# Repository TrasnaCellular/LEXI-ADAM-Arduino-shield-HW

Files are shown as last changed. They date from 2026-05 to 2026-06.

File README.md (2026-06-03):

# Trasna LEXI-R10 Arduino schield board

The LEXI-ADAM UNO Shield is an open-source cellular expansion board for the Arduino UNO or Arduino UNO Q platforms. It uses the ultra-small LEXI-R10 series or ADAM-R11 series LTE Cat 1bis cellular modules. 

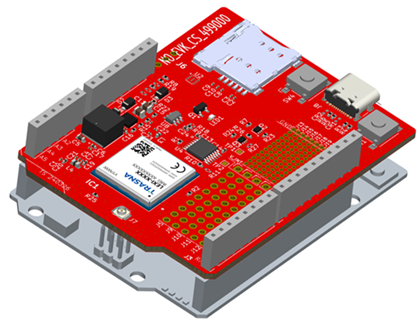
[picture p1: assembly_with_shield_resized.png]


The Cellular module can be turned ON/OFF and Reset by the Arduino board. The shield has its own step down to deliver power to the cellular module; the stepdown too can be turned ON/OFF by an Arduino GPIO to minimise power consumption. The input voltage range of the shield is the same as Arduino's range. 

The Arduino UNO  communicates with the Cellular module via UART, and by default, this communication is without RTS/CTS handshake. The shield already supports RTS/CTS handshake by easy soldering jumpers. The proper modifications must be made also to the MCU firmware of Arduino (R7FA4M1AB3CFM for UNO, or STM32U585 for UNO Q) to support hardware handshake. To achieve communication with the Linux system of Arduino UNO Q, the Arduino Bridge feature should be used. For even higher higher communication rates with the Linux system the USB port of the UNO Q must be connected to the USB port of the shield.
 
The shield also features two breadboarding areas for experimenting with own circuits. They have 2.54mm and 1.27mm pitch and are provided with 3.3Volts, 1.8Volts and GND for powering the circuits that the user might implement.

All the hardware design source files, including Schematic, PCB board, gerbers, stack-up, can be downloaded from the present repository. Also the firmware examples running on Arduino UNO R4 WIFI and on Arduino UNO Q can be found here.

The user guide explaining the board can be downloaded from: [LEXI-ADAM_Arduino_UNO_Shield_UserGuide](https://drive.google.com/file/d/1tEk1xlIRyrKd_FjjbZdSfsDOfKxhqTxc/view).

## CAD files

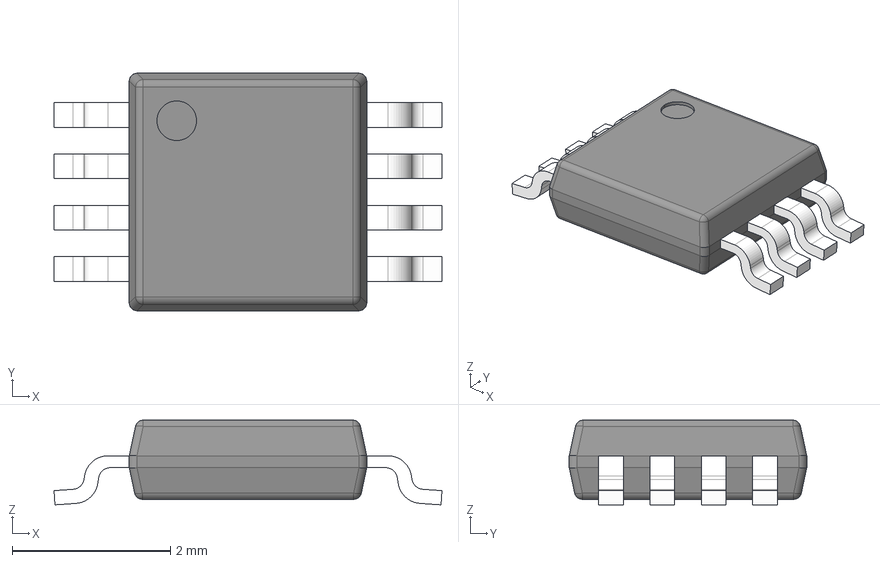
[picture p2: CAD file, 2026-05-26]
shield_design_library/3D/DGN0008G.stp
4.90 x 3.00 x 1.07 mm
BODY-DGN0008G
LEAD-DGN0008G x 8
PIN1_DGN0008G
DAP_DGN0008G

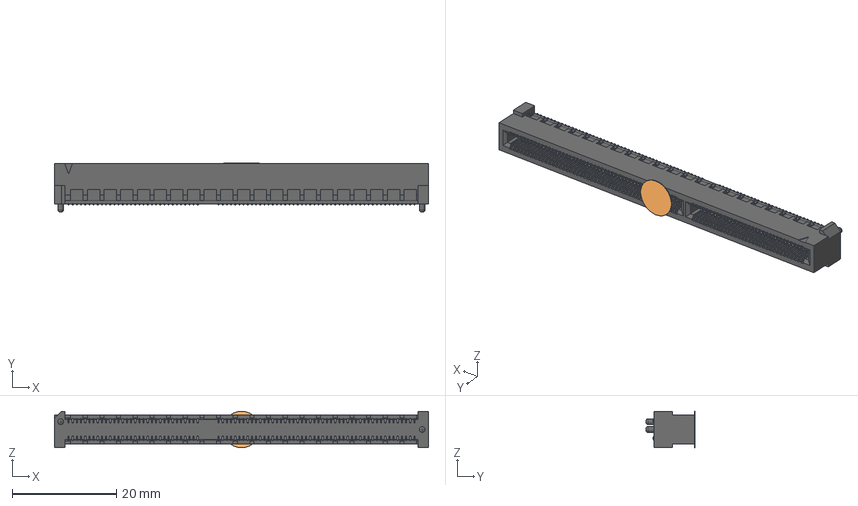
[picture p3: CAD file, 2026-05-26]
shield_design_library/3D/HSEC8-180-01-L-DV-A.step
71.8 x 9.43 x 7.01 mm
HSEC8-180-01-L-DV-A-Kter
C-188-02-Pin-32--L-01
C-188-02-Pin-32--L-012
C-188-02-Pin-48--L-01
C-188-02-Pin-48--L-012

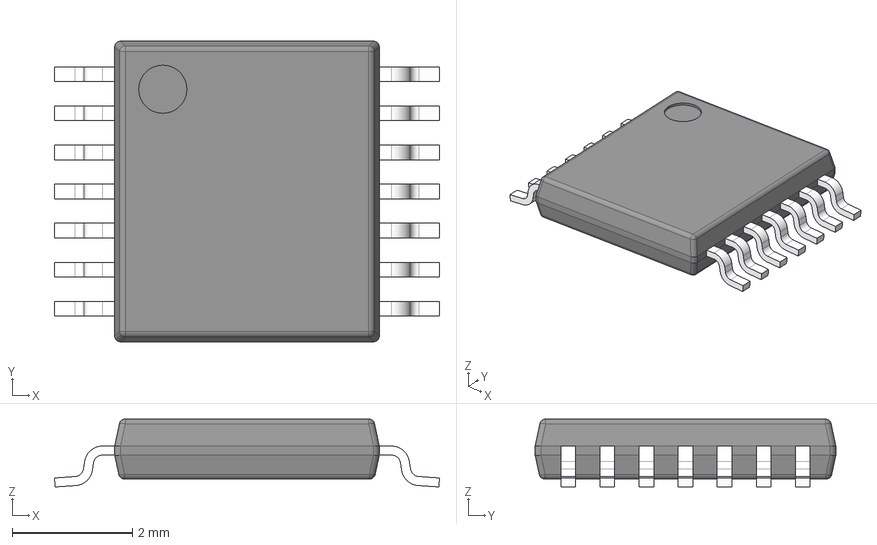
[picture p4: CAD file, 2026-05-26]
shield_design_library/3D/PW0014A.stp
6.40 x 5.00 x 1.13 mm
BODY-TSSOP
LEAD-TSSOP x 14
PIN1

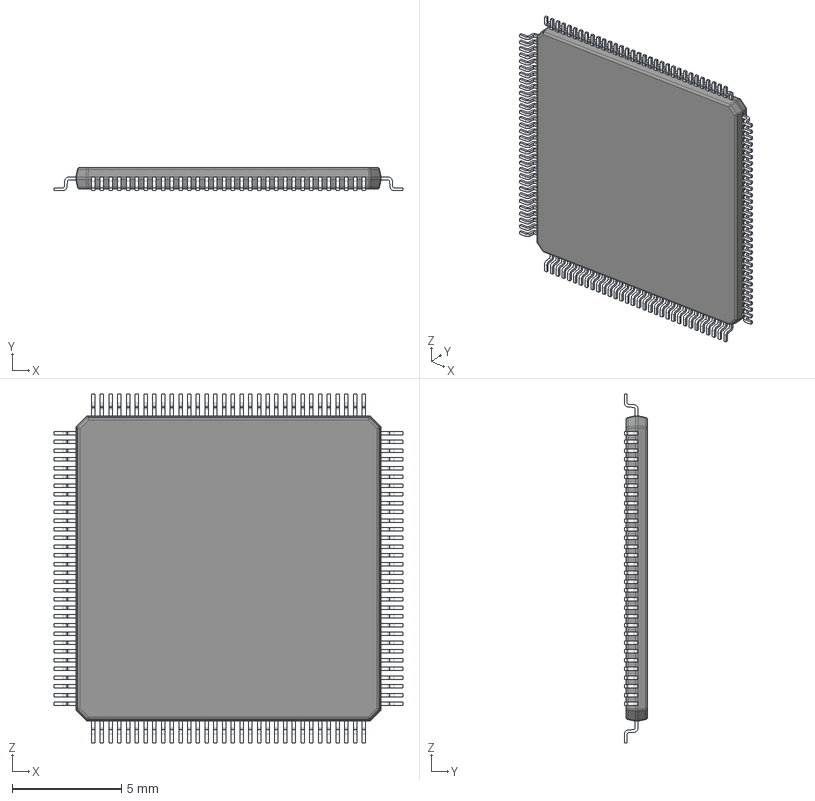
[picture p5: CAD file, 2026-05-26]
shield_design_library/3D/PDT0128A.stp
16.0 x 1.07 x 16.0 mm
BODY_VJX128A
LEAD_VJX128A x 128

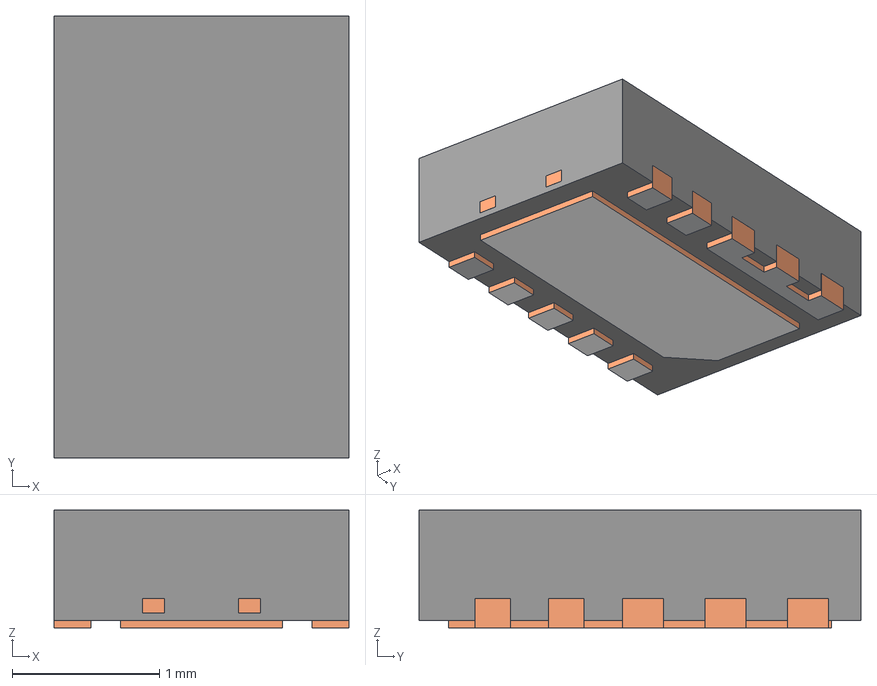
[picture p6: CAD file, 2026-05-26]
shield_design_library/3D/DML0010A.stp
2.00 x 3.00 x 0.8 mm
BODY-SON
FRAME-DML0010A
PIN1-ID

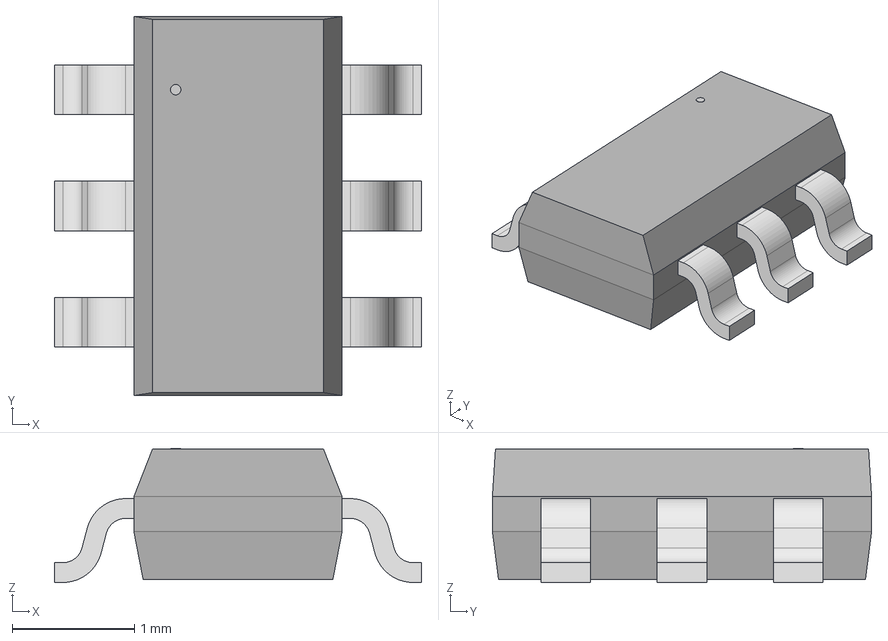
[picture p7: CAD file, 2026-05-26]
shield_design_library/3D/74LVC2G07GV_125_NEX.step
3.00 x 3.10 x 1.09 mm

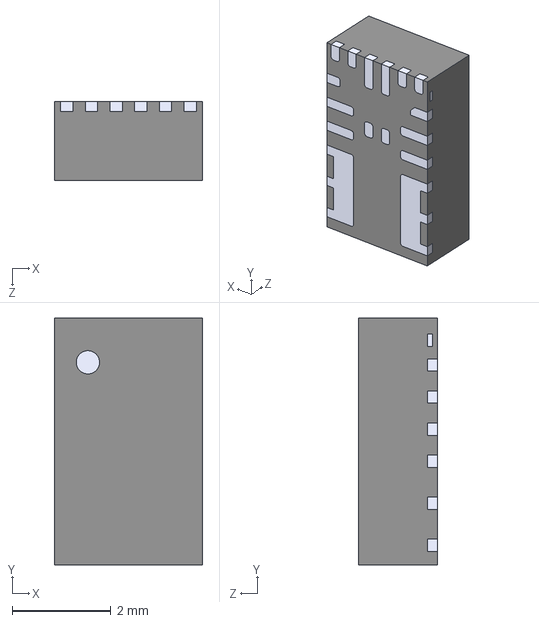
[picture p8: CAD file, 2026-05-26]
shield_design_library/3D/MPM3606AGQV.step
3.00 x 5.00 x 1.60 mm

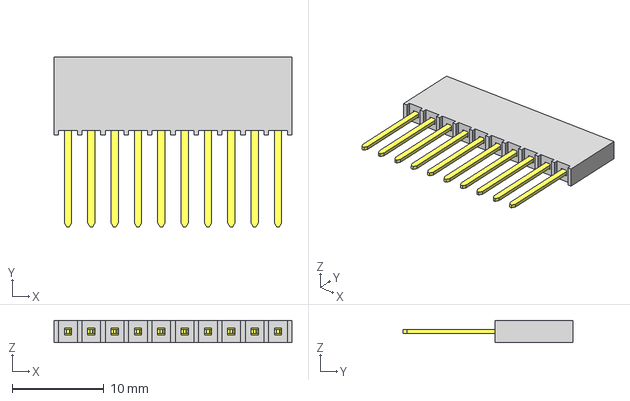
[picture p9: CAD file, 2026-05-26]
shield_design_library/3D/SSW-110-03-L-S.stp
25.9 x 18.5 x 2.41 mm
T1SSW-110-03-L-S
P2SSW-110-03-L-S

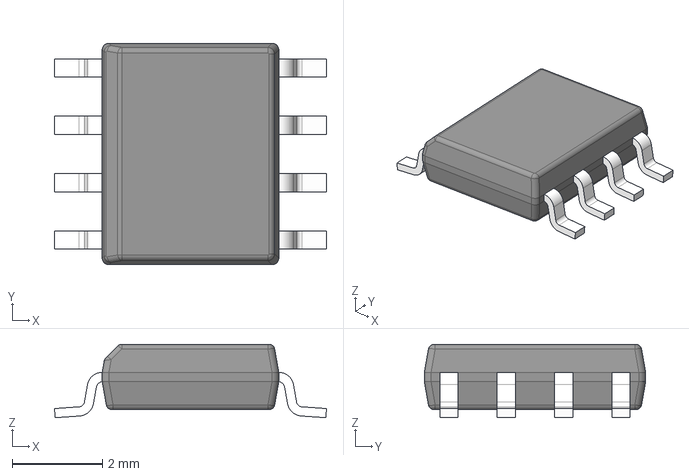
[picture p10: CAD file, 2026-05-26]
shield_design_library/3D/D0008A.stp
6.02 x 4.90 x 1.63 mm
BODY-SO
LEAD-D0008A x 8

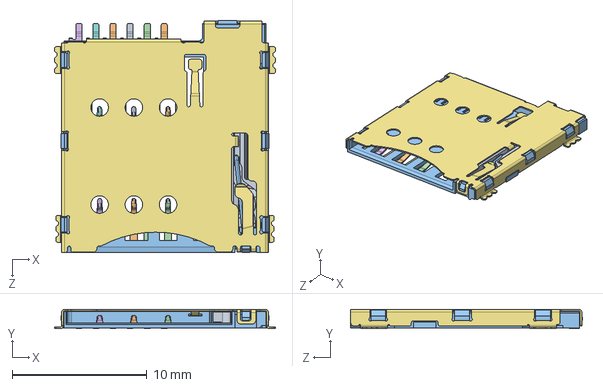
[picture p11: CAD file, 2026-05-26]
shield_design_library/3D/MSIM-2-A.stp
16.4 x 1.44 x 17.2 mm

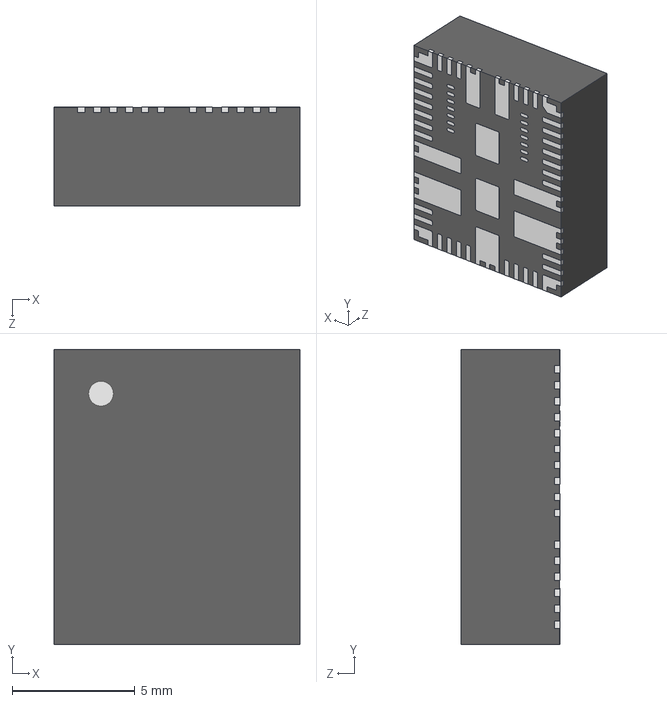
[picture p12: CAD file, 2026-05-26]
shield_design_library/3D/MPM3695GRF-25.step
10.0 x 12.0 x 4.01 mm

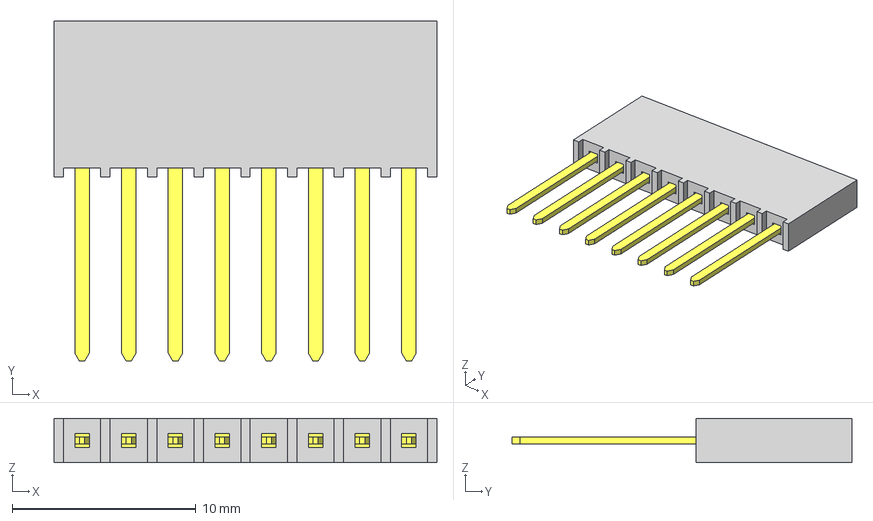
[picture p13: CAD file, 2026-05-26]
shield_design_library/3D/SSW-108-03-G-S.stp
20.8 x 18.5 x 2.41 mm
T1SSW-108-03-G-S
P2SSW-108-03-G-S

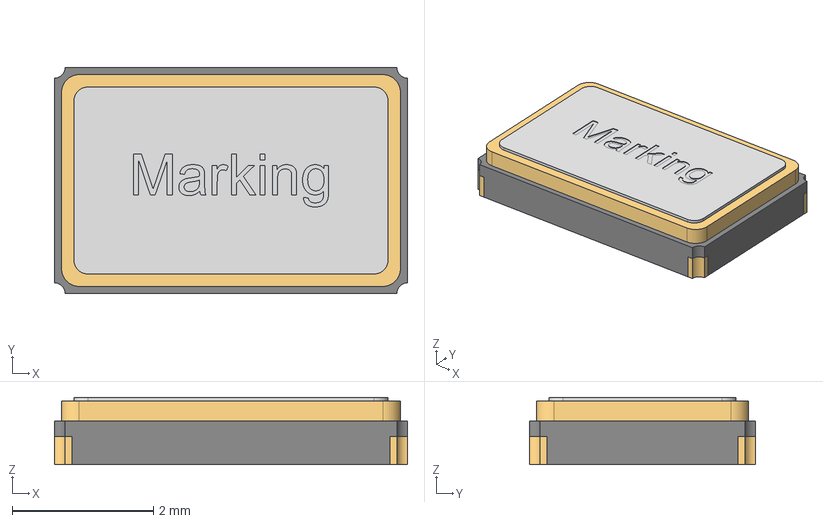
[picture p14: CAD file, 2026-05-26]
shield_design_library/3D/Download_STP_830059528 (rev1).stp
5.00 x 3.20 x 0.95 mm
Pins
Cover

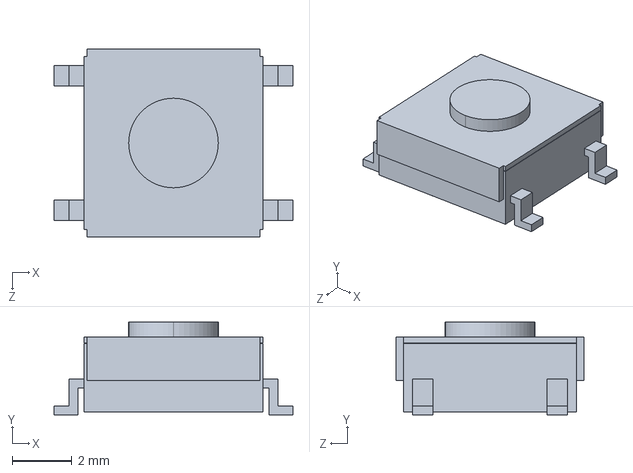
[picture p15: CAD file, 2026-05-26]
shield_design_library/3D/B3FS_1000.step
8.00 x 3.10 x 6.30 mm

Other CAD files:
shield_design_library/3D/DRL0006A.stp
shield_design_library/3D/21-0076E_MXM.step
shield_design_library/3D/CT3151-0.stp
shield_design_library/3D/CT3151-2.stp
shield_design_library/3D/Crystal_SMD_Abracon_ABM3B-4Pin_5.0x3.2mm.step
shield_design_library/3D/DCK0005A.stp
shield_design_library/3D/DDA0008J.stp
shield_design_library/3D/DGK0008A.stp
shield_design_library/3D/DRR0012G.stp
shield_design_library/3D/IND_BLM15_0402_MUR.step
shield_design_library/3D/IND_BLM18_0603_MUR.step
shield_design_library/3D/IND_IFSC-2020DE-01_VIS.step
shield_design_library/3D/LED_LTST-C190_LTO.step
shield_design_library/3D/LTST-C190KRKT.stp
shield_design_library/3D/LexiWithLabelTrasna.step
shield_design_library/3D/MAX4594EXK-T.step
shield_design_library/3D/MICROPAK6_1X1P45_ONS.step
shield_design_library/3D/PBS0032A.stp
shield_design_library/3D/PESD0402-140_LTF.step
shield_design_library/3D/QFN32_5X5MC_MCH.step
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

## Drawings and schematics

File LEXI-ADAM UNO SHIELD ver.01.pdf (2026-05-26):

1 | 2 | 3 | 4 | 5 | 6

A

BC

D

A

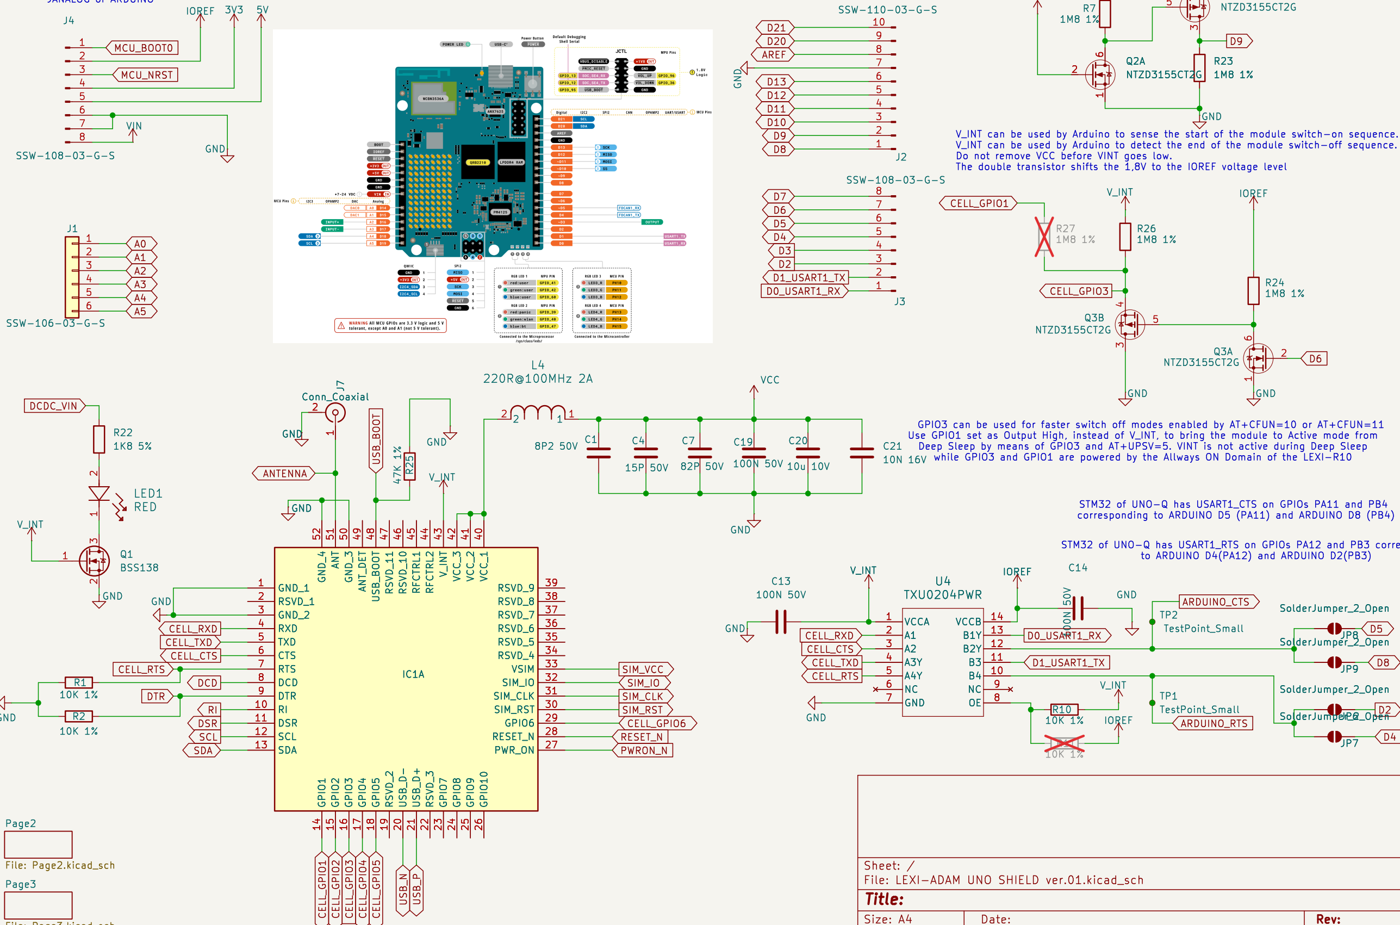
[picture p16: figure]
220R@100MHz; GND; J1 SSW-106-03-G-S; 8P2 50V GND; J4 SSW-108-03-G-S; IOREF 3V3; R²⁵ 47K ¹%; V_INT ² 1; LED1 RED; 82P 50V GND; VIN; CELL_GPIO3 SCL SDA CELL_TXD; PWRON_N; SIM_CLK; SIM_IO; CELL_RTS CELL_RXD; CELL_TXD; CELL_CTS; SIM_RST; CELL_GPIO1 DCD; ARDUINO_CTS CELL_GPIO6 SIM_VCC USB_P; ARDUINO_RTS DTR; D8D2D4 CELL_RTS; CELL_GPIO¹; D5 USB_N; ANTENNA RI; D6 DSR 2 GNDGND; V_INT; IOREF U4 TXU0204PWR; JP8 SolderJumper_2_Open; JP9 SolderJumper_2_Open; Q2A NTZD3155CT2G 2
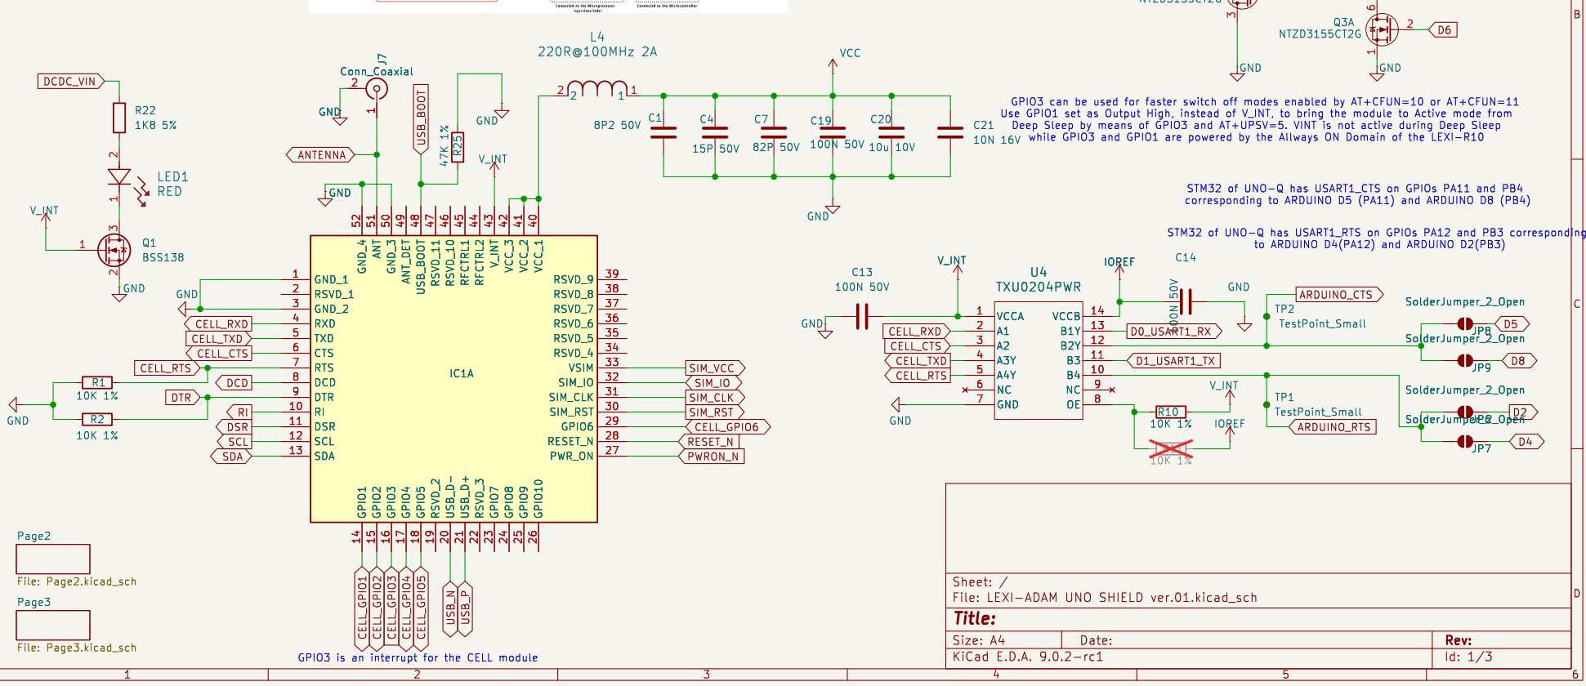
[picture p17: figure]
D Date: KiCad; E.D.A. 9.0.2-rc1 Size: A4; Rev:; Page2 File: Page2.kicad_sch; 50V GND; GND; J7 Conn_Coaxial R22; V_INT; VCC; 3 2 Q1 BSS138 R1; IOREF R10 10K 1%; V_INT R11; IOREF; V_INT C13; TP2 TestPoint_Small C14 100N ⁵⁰V; JP8 SolderJumper_2_Open TP1 TestPoint_Small; JP7 SolderJumper_2_Open JP6 SolderJumper_2_Open; JP9 SolderJumper_2_Open GND; 6 1 Q3A NTZD3155CT2G; CELL_RXD; D0_USART1_RX D1_USART1_TX CELL_CTS; RESET_N

Id: 1/3 Title: File: LEXI-ADAM | UNO SHIELD ver.01.kicad_sch Sheet: / Page3 File: Page3.kicad_sch
GND GND_1 1 | RSVD_1 2 | GND_2 3 | RXD 4 | TXD 5 | CTS 6 | RTS 7 | DCD 8 | DTR 9 | RI 10 DSR 11 SCL 12 SDA 13 | GND_4 52 GPIO¹ 14 | ANT 51 GPIO² 15 | GND_3 50 GPIO³ 16 | ANT_DET 49 GPIO⁴ 17 | USB_BOOT 48 GPIO⁵ 18 | RSVD_11 47 RSVD_2 19 | RSVD_10 46 USB_D⁻ 20 | RFCTRL1 45 USB_D⁺ 21 | RFCTRL2 44 RSVD_3 22 | V_INT 43 GPIO⁷ 23 | VCC_3 42 GPIO⁸ 24 | VCC_2 41 GPIO⁹ 25 | VCC_1 40 GPIO¹⁰ 26 | RSVD_9 39 RSVD_8 38 RSVD_7 37 RSVD_6 36 RSVD_5 35 RSVD_4 34 VSIM 33 SIM_IO 32 SIM_CLK 31 SIM_RST 30 GPIO6 29 RESET_N 28 PWR_ON 27

1
2
3
4
5
6
5

4 3 Q3B NTZD3155CT2G

VCCA 1 | A1 2 | A2 3 | A3Y 4 | A4Y 5 | NC 6 | GND 7 | VCCB 14 B1Y 13 B2Y 12 B3 11 B4 10 NC 9 OE 8 U4 TXU0204PWR

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
J3 SSW-108-03-G-S

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
J2 SSW-110-03-G-S | R27

1M8 1%

# V_INT R7

1M8 1%

IOREF V_INT | R23

1M8 1%

5

4 3 Q2B NTZD3155CT2G

2

6 1 Q2A NTZD3155CT2G

GND

IOREF R26

1M8 1%

R24
1M8 1%
D6 D5 A2 | D21 D20 D12 D13 AREF D8 D11 D10D9 D1_USART1_TX D2 D4 D0_USART1_RX D7 A0 MCU_BOOT0 | USB_BOOT MCU_NRST A5 | D9 A1A3A4 DCDC_VIN | CELL_GPIO² CELL_GPIO³ CELL_GPIO⁴ CELL_GPIO⁵
D3 GPIO3 is an interrupt | for the CELL module | STM32 of UNO-Q has USART1_CTS on GPIOs PA11 and PB4
corresponding | to ARDUINO D5 (PA11) and ARDUINO D8 (PB4) STM32 of UNO-Q has USART1_RTS on GPIOs PA12 and PB3 corresponding
to ARDUINO D4(PA12) and ARDUINO D2(PB3) GPIO3 can be used for faster switch off modes enabled by AT+CFUN=10 | or AT+CFUN=11

JANALOG of ARDUINO

V_INT can be used by Arduino to sense the start of the module switch-on | sequence. V_INT can be used by Arduino to detect the end of the module switch-off | sequence. Do not remove VCC before VINT goes low. The double transistor | shifts the 1,8V to the IOREF voltage level Use GPIO1 set as Output High, instead of V_INT, to bring the module to Active mode from

Deep Sleep by means of GPIO3 and AT+UPSV=5. VINT is not active during Deep Sleep while GPIO3 and GPIO1 are powered by the Allways ON Domain of the LEXI-R10

IC1A GND_1 1 | RSVD_1 2 | GND_2 3 | RXD 4 | TXD 5 | CTS 6 | RTS 7 | DCD 8 | DTR 9 | RI 10 DSR 11 SCL 12 SDA 13 | GND_4 52 GPIO¹ 14 | ANT 51 GPIO² 15 | GND_3 50 GPIO³ 16 | ANT_DET 49 GPIO⁴ 17 | USB_BOOT 48 GPIO⁵ 18 | RSVD_11 47 RSVD_2 19 | RSVD_10 46 USB_D⁻ 20 | RFCTRL1 45 USB_D⁺ 21 | RFCTRL2 44 RSVD_3 22 | V_INT 43 GPIO⁷ 23 | VCC_3 42 GPIO⁸ 24 | VCC_2 41 GPIO⁹ 25 | VCC_1 40 GPIO¹⁰ 26 | RSVD_9 39 RSVD_8 38 RSVD_7 37 RSVD_6 36 RSVD_5 35 RSVD_4 34 VSIM 33 SIM_IO 32 SIM_CLK 31 SIM_RST 30 GPIO6 29 RESET_N 28 PWR_ON 27 J7 Conn_Coaxial 1
VCCA 1 | A1 2 | A2 3 | A3Y 4 | A4Y 5 | NC 6 | GND 7 | VCCB 14 B1Y 13 B2Y 12 B3 11 B4 10 NC 9 OE 8

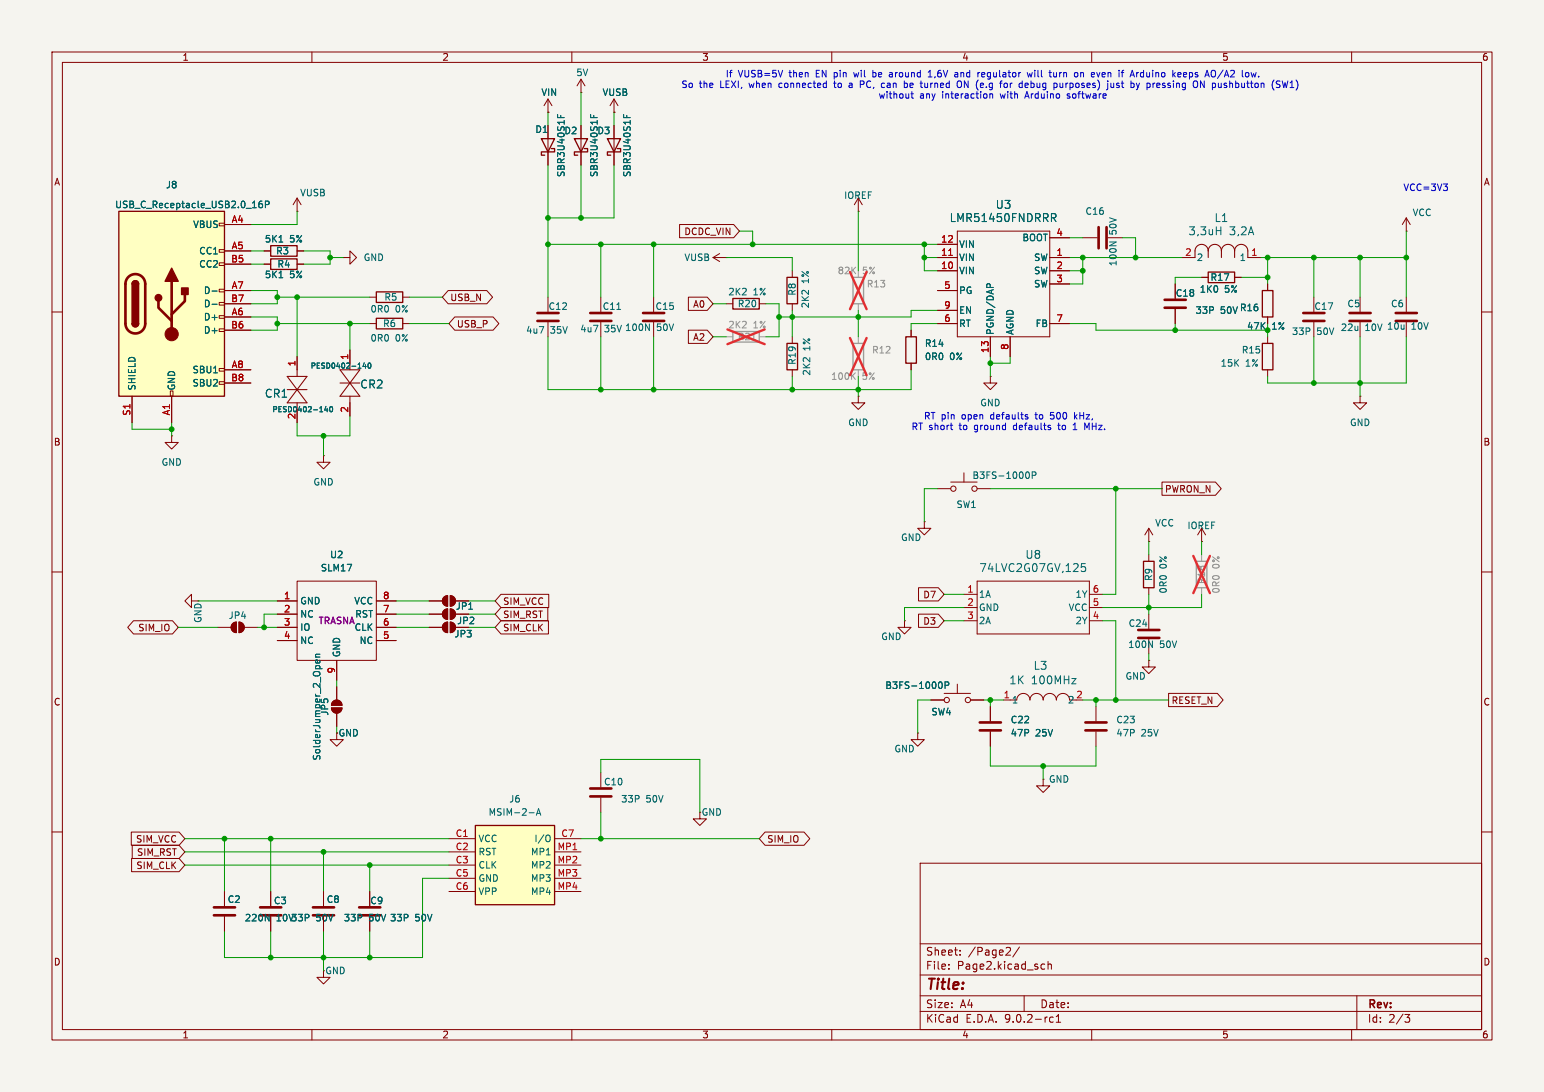
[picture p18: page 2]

8 PGND/DAP 13 VIN 12 VIN 11 VIN 10 PG 5 EN 9 RT 6 U3
LMR51450FNDRRR

8 PGND/DAP 13 VIN 12 VIN 11 VIN 10 PG 5 EN 9 RT 6 C18

9 VCC 8 RST 7 CLK 6 NC 5 U2 SLM17 TRASNA GND

9 VCC 8 RST 7 CLK 6 NC 5

VCC C1 RST C2 CLK C3 GND C5 VPP C6

Id: 2/3 Title: File: Page2.kicad_sch Sheet: /Page2/ C2

# J11 SSW-110-03-G-S

# J12 SSW-110-03-G-S

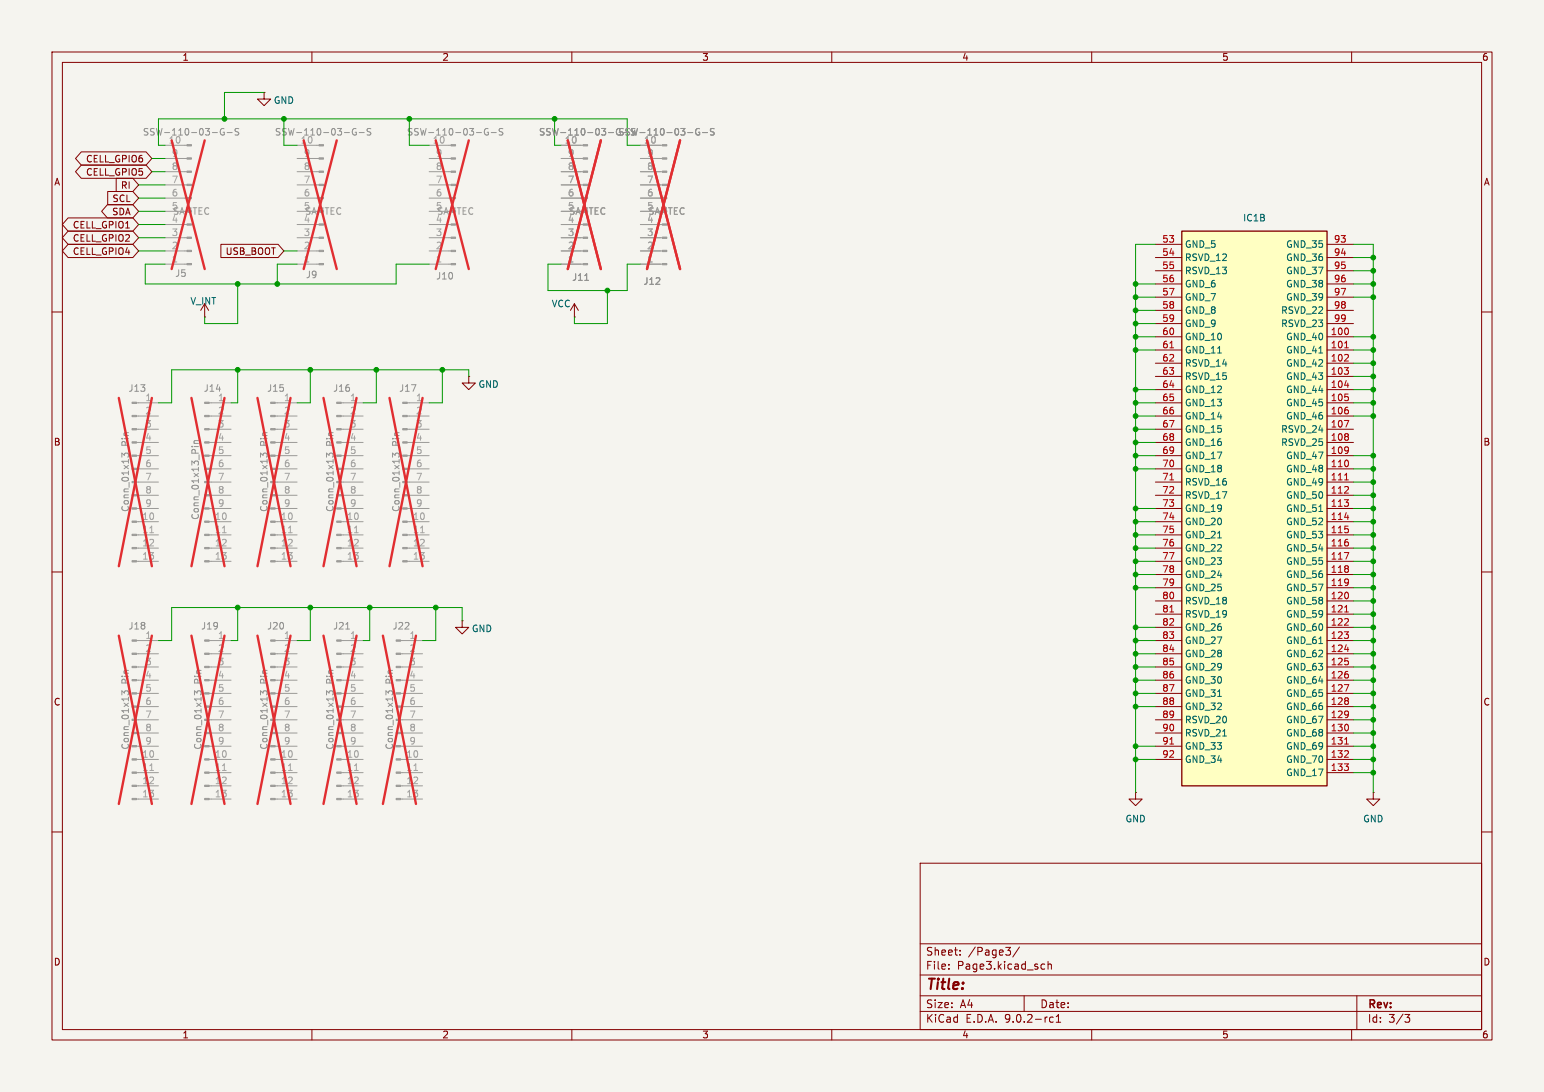
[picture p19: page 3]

Id: 3/3 Title: File: Page3.kicad_sch Sheet: /Page3/ ¹²³⁴⁵⁶⁷⁸⁹

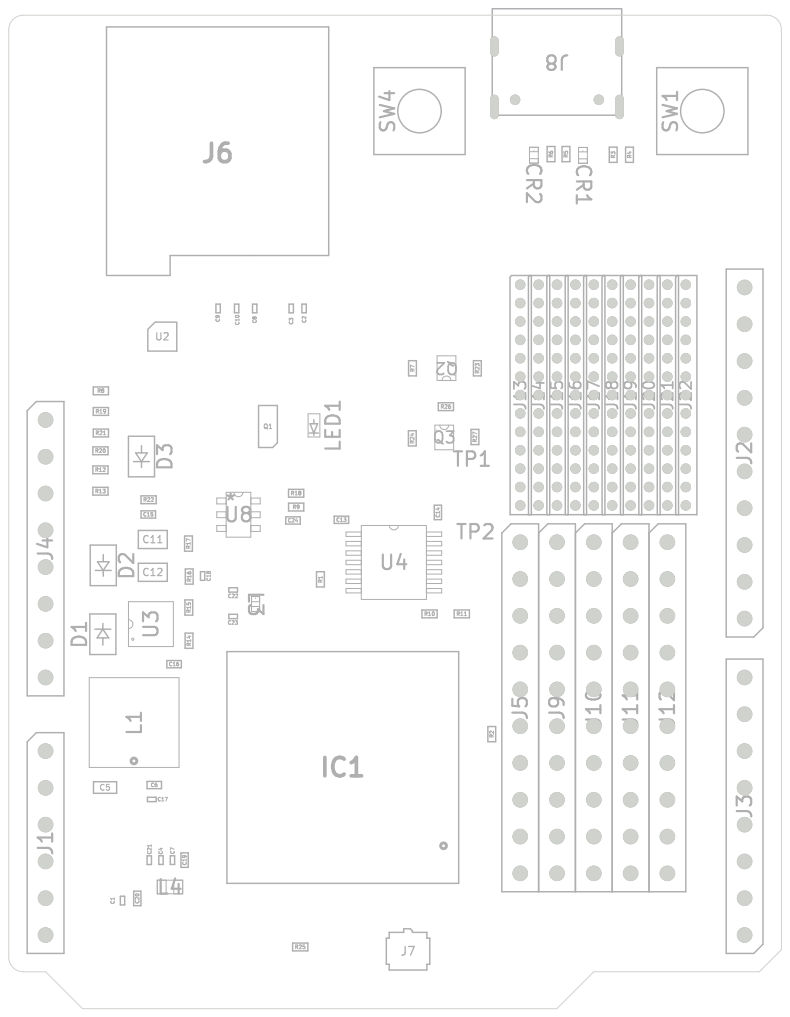
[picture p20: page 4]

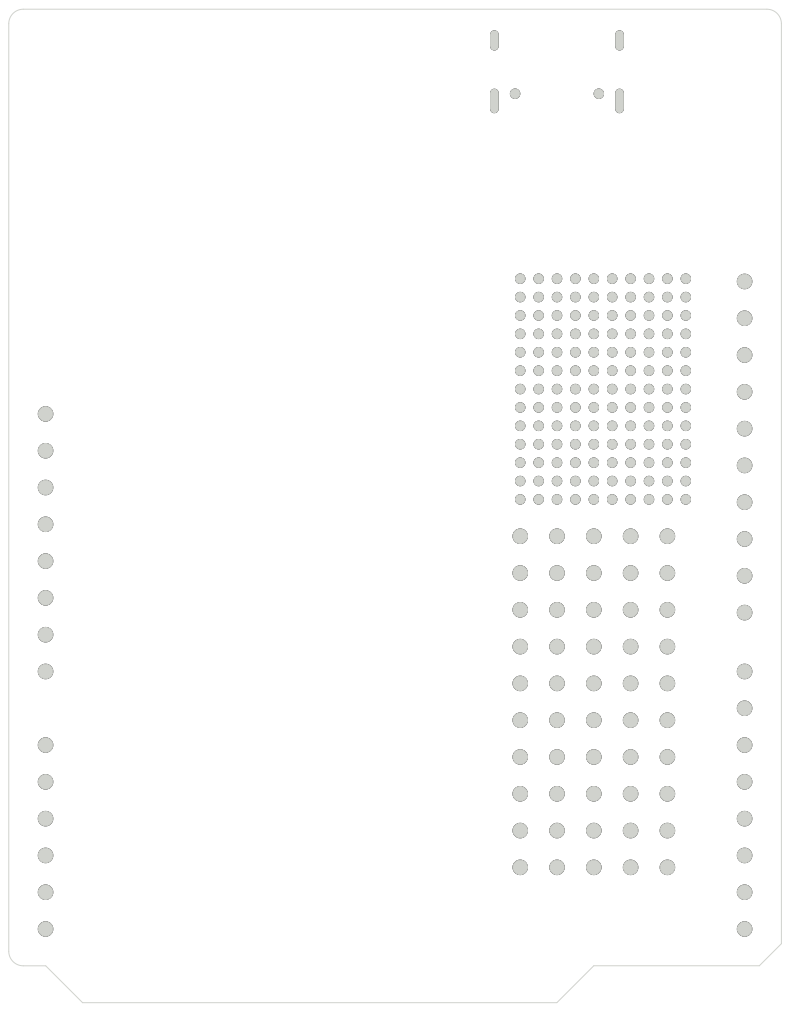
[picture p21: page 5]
D Date: KiCad; E.D.A. 9.0.2-rc1 Size: A4; Rev:; Id: 1/1 Title: File: LEXI-ADAM; UNO SHIELD ver.01.kicad_pcb Sheet:

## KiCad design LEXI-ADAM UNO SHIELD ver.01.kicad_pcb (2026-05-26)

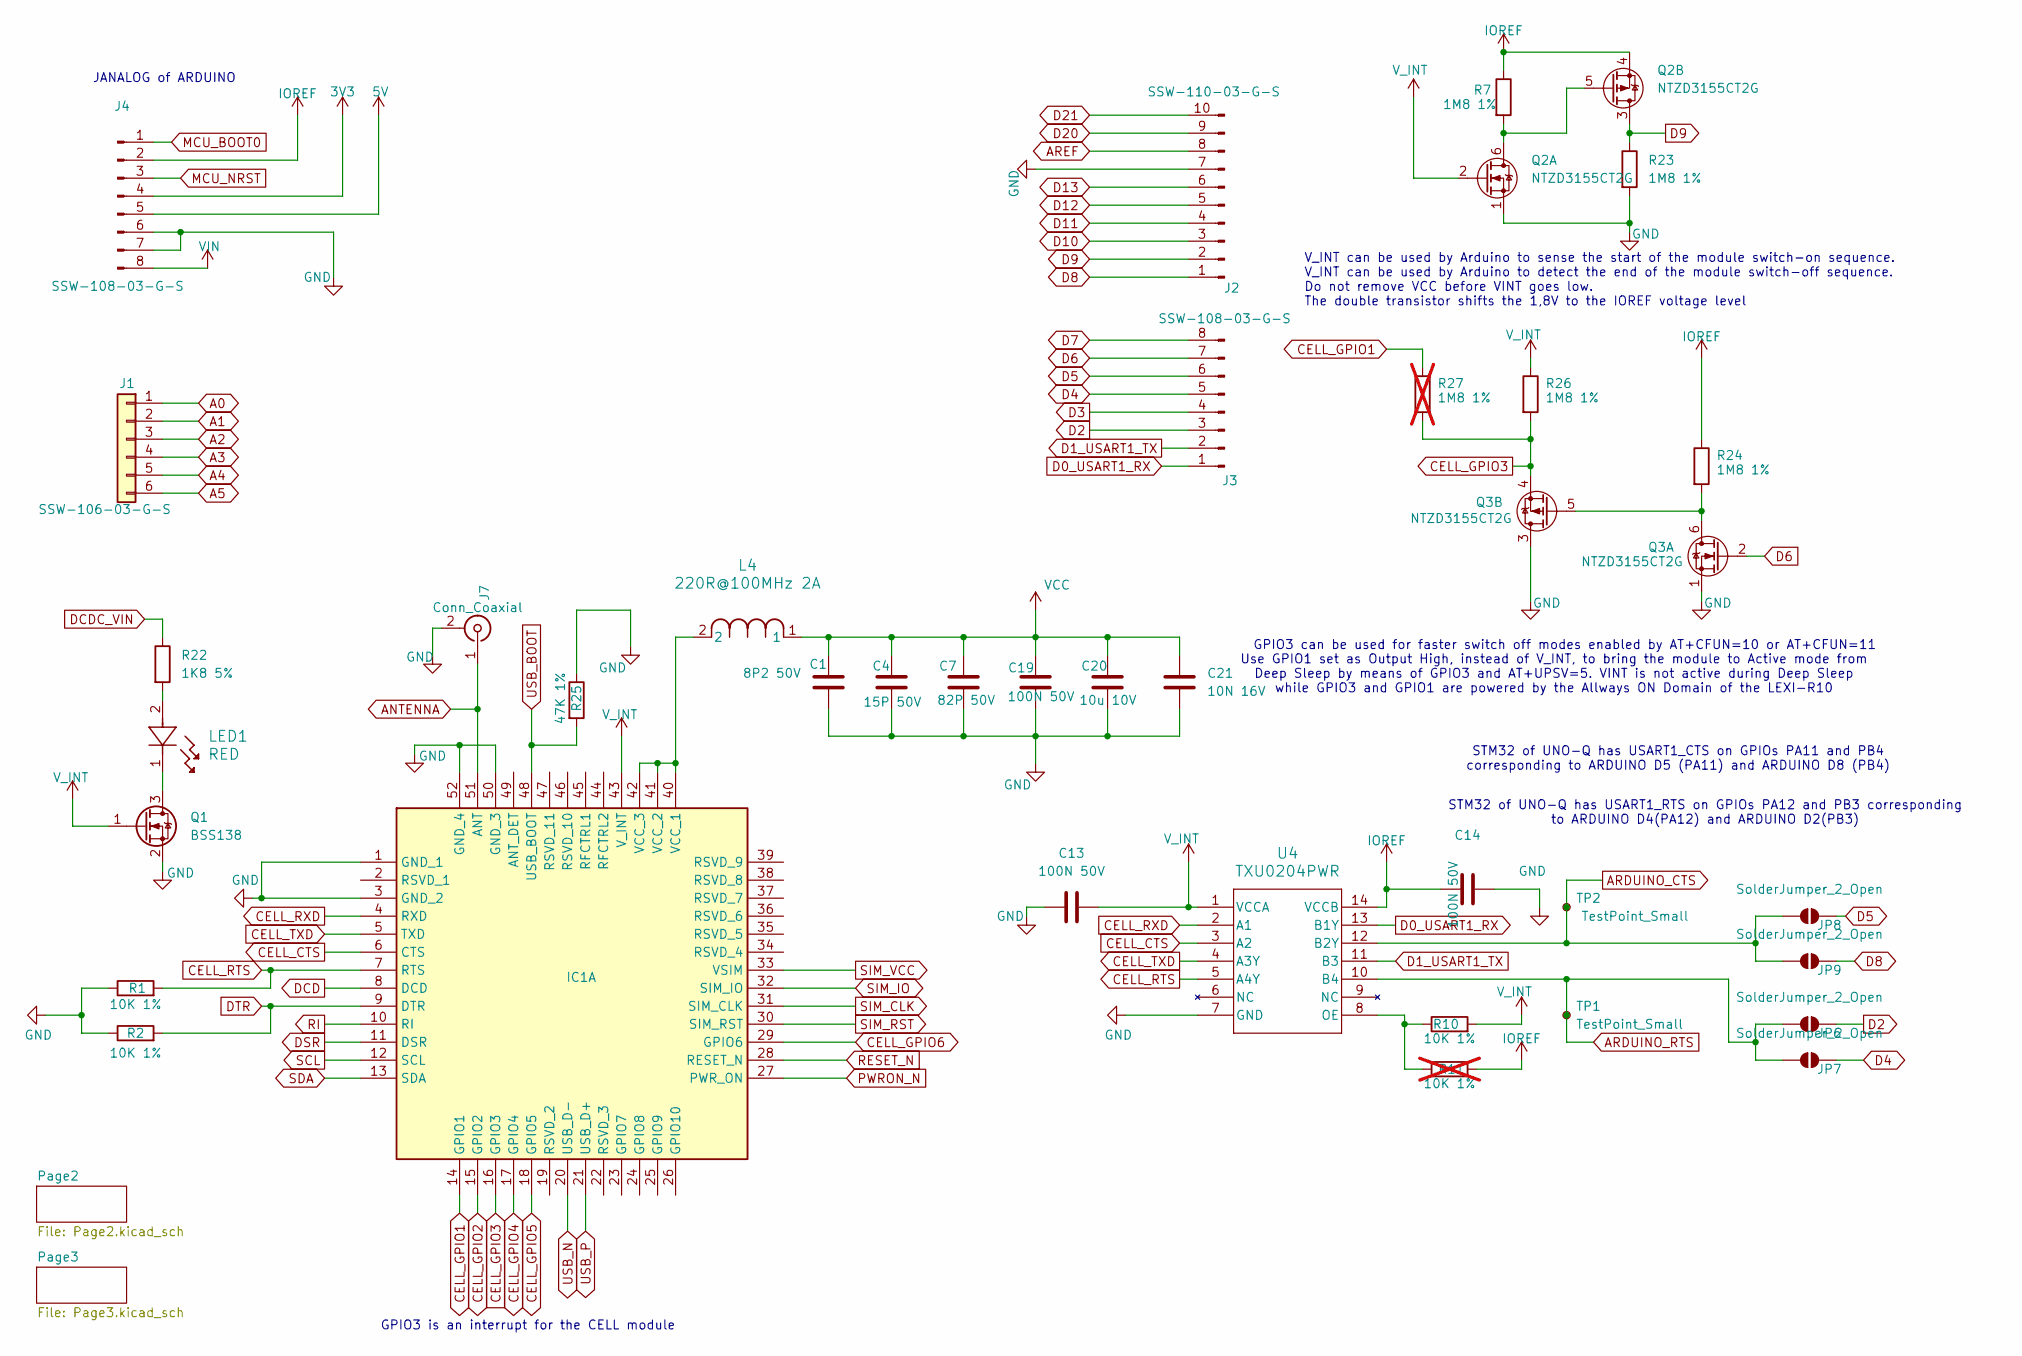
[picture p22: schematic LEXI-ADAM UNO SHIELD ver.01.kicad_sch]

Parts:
C1: 8P2 50V; C_0201_0603Metric; Manufacturer_Part_Number GRM0335C1H8R2DA01D
C4: 15P 50V; C_0201_0603Metric; Manufacturer_Part_Number GRM0335C1H150JA01D
C7: 82P 50V; C_0201_0603Metric; Manufacturer_Part_Number GRM0335C1H820JA01D
C13, C14, C19: 100N 50V; C_0402_1005Metric; Manufacturer_Part_Number GRM155R61H104KE14D
C20: 10u 10V; C_0402_1005Metric; Manufacturer_Part_Number GRM155R61A106ME11D
C21: 10N 16V; C_0201_0603Metric; Manufacturer_Part_Number GRM033R71C103KE14D
IC1: LEXI-R10011D; LEXIR10801D00B00; Manufacturer_Part_Number LEXI-R10011D
J1: SSW-106-03-G-S; Manufacturer_Part_Number SSW-106-03-G-S
J2: SSW-110-03-G-S; SSW-110-03-L-S; Manufacturer_Part_Number SSW-110-03-G-S
J3, J4: SSW-108-03-G-S; Manufacturer_Part_Number SSW-108-03-G-S
J7: Conn_Coaxial; U.FL_Hirose_U.FL-R-SMT-1_Vertical; Manufacturer_Part_Number CONUFL001-SMD-T
JP6, JP7, JP8, JP9: SolderJumper_2_Open; SolderJumper-2_P1.3mm_Open_RoundedPad1.0x1.5mm
L4: 220R@100MHz 2A; IND_BLM18_0603_MUR; Manufacturer_Part_Number BLM18EG221SN1D
LED1: RED; LED_LTST-C190_LTO; Manufacturer_Part_Number LTST-C190KRKT
Q1: BSS138; SOT-23; Manufacturer_Part_Number BSS138P,215
Q2, Q3: NTZD3155CT2G; SOT-563-6_1P3X1P7_ONS; Manufacturer_Part_Number NTZD3155CT2G
R1, R2, R10: 10K 1%; R_0402_1005Metric; Manufacturer_Part_Number RK73H1ETTP1002F
R7, R23, R24, R26: 1M8 1%; R_0402_1005Metric; Manufacturer_Part_Number CRCW04021M80FKEDC
R11: 10K 1%; R_0402_1005Metric; Manufacturer_Part_Number RK73H1ETTP1002F; not fitted
R22: 1K8 5%; R_0402_1005Metric; Manufacturer_Part_Number AC0402JR-071K8L
R25: 47K 1%; R_0402_1005Metric; Manufacturer_Part_Number RK73H1ETTP4702F
R27: 1M8 1%; R_0402_1005Metric; Manufacturer_Part_Number CRCW04021M80FKEDC; not fitted
TP1, TP2: TestPoint_Small; TestPoint_Pad_1.0x1.0mm
U4: TXU0204PWR; TSSOP14_PW_TEX; Manufacturer_Part_Number TXU0204PWR

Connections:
3V3: J4.4
5V: J4.5; also elsewhere on the board
A0: J1.1; also elsewhere on the board
A1: J1.2
A2: J1.3; also elsewhere on the board
A3: J1.4
A4: J1.5
A5: J1.6
ANTENNA: IC1.51 (ANT), J7.1 (In)
ARDUINO_CTS: JP8.1 (A), JP9.1 (A), TP2.1, U4.12 (B2Y)
ARDUINO_RTS: JP6.1 (A), JP7.1 (A), TP1.1, U4.10 (B4)
AREF: J2.8
CELL_CTS: IC1.6 (CTS), U4.3 (A2)
CELL_GPIO1: IC1.14 (GPIO1), R27.1; also elsewhere on the board
CELL_GPIO2: IC1.15 (GPIO2); also elsewhere on the board
CELL_GPIO3: IC1.16 (GPIO3), Q3.4 (SP), R26.2, R27.2
CELL_GPIO4: IC1.17 (GPIO4); also elsewhere on the board
CELL_GPIO5: IC1.18 (GPIO5); also elsewhere on the board
CELL_GPIO6: IC1.29 (GPIO6); also elsewhere on the board
CELL_RTS: IC1.7 (RTS), R1.2, U4.5 (A4Y)
CELL_RXD: IC1.4 (RXD), U4.2 (A1)
CELL_TXD: IC1.5 (TXD), U4.4 (A3Y)
D0_USART1_RX: J3.1, U4.13 (B1Y)
D1_USART1_TX: J3.2, U4.11 (B3)
D2: J3.3, JP6.2 (B)
D3: J3.4; also elsewhere on the board
D4: J3.5, JP7.2 (B)
D5: J3.6, JP8.2 (B)
D6: J3.7, Q3.2 (GN)
D7: J3.8; also elsewhere on the board
D8: J2.1, JP9.2 (B)
D9: J2.2, Q2.3 (DP), R23.1
D10: J2.3
D11: J2.4
D12: J2.5
D13: J2.6
D20: J2.9
D21: J2.10
DCD: IC1.8 (DCD)
DCDC_VIN: R22.1; also elsewhere on the board
DSR: IC1.11 (DSR)
DTR: IC1.9 (DTR), R2.2
GND: C1.1, C4.2, C7.2, C13.2, C14.1, C19.2, C20.2, C21.2, IC1.1 (GND_1), IC1.3 (GND_2), IC1.50 (GND_3), IC1.52 (GND_4), J2.7, J4.6, J4.7, J7.2 (Ext), Q1.2 (S), Q2.1 (SN), Q3.1 (SN), Q3.3 (DP), R1.1, R2.1, R23.2, R25.1, U4.7 (GND); also elsewhere on the board
IOREF: C14.2, J4.2, Q2.4 (SP), R7.1, R11.2, R24.1, U4.14 (VCCB); also elsewhere on the board
MCU_BOOT0: J4.1
MCU_NRST: J4.3
unnamed: IC1.40 (VCC_1), IC1.41 (VCC_2), IC1.42 (VCC_3), L4.2
unnamed: LED1.2, R22.2
unnamed: LED1.1, Q1.3 (D)
unnamed: Q2.5 (GP), Q2.6 (DN), R7.2
unnamed: Q3.5 (GP), Q3.6 (DN), R24.2
unnamed: R10.1, R11.1, U4.8 (OE)
PWRON_N: IC1.27 (PWR_ON); also elsewhere on the board
RESET_N: IC1.28 (RESET_N); also elsewhere on the board
RI: IC1.10 (RI); also elsewhere on the board
SCL: IC1.12 (SCL); also elsewhere on the board
SDA: IC1.13 (SDA); also elsewhere on the board
SIM_CLK: IC1.31 (SIM_CLK); also elsewhere on the board
SIM_IO: IC1.32 (SIM_IO); also elsewhere on the board
SIM_RST: IC1.30 (SIM_RST); also elsewhere on the board
SIM_VCC: IC1.33 (VSIM); also elsewhere on the board
USB_BOOT: IC1.48 (USB_BOOT), R25.2; also elsewhere on the board
USB_N: IC1.20 (USB_D-); also elsewhere on the board
USB_P: IC1.21 (USB_D+); also elsewhere on the board
VCC: C1.2, C4.1, C7.1, C19.1, C20.1, C21.1, L4.1; also elsewhere on the board
VIN: J4.8; also elsewhere on the board
V_INT: C13.1, IC1.43 (V_INT), Q1.1 (G), Q2.2 (GN), R10.2, R26.1, U4.1 (VCCA); also elsewhere on the board

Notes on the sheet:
V_INT can be used by Arduino to sense the start of the module switch-on sequence. V_INT can be used by Arduino to detect the end of the module switch-off sequence. Do not remove VCC before VINT goes low. The double transistor shifts the 1,8V to the IOREF voltage level
Use GPIO1 set as Output High, instead of V_INT, to bring the module to Active mode from Deep Sleep by means of GPIO3 and AT+UPSV=5. VINT is not active during Deep Sleep while GPIO3 and GPIO1 are powered by the Allways ON Domain of the LEXI-R10
JANALOG of ARDUINO
GPIO3 can be used for faster switch off modes enabled by AT+CFUN=10 or AT+CFUN=11
STM32 of UNO-Q has USART1_CTS on GPIOs PA11 and PB4 corresponding to ARDUINO D5 (PA11) and ARDUINO D8 (PB4)
STM32 of UNO-Q has USART1_RTS on GPIOs PA12 and PB3 corresponding to ARDUINO D4(PA12) and ARDUINO D2(PB3)
GPIO3 is an interrupt for the CELL module

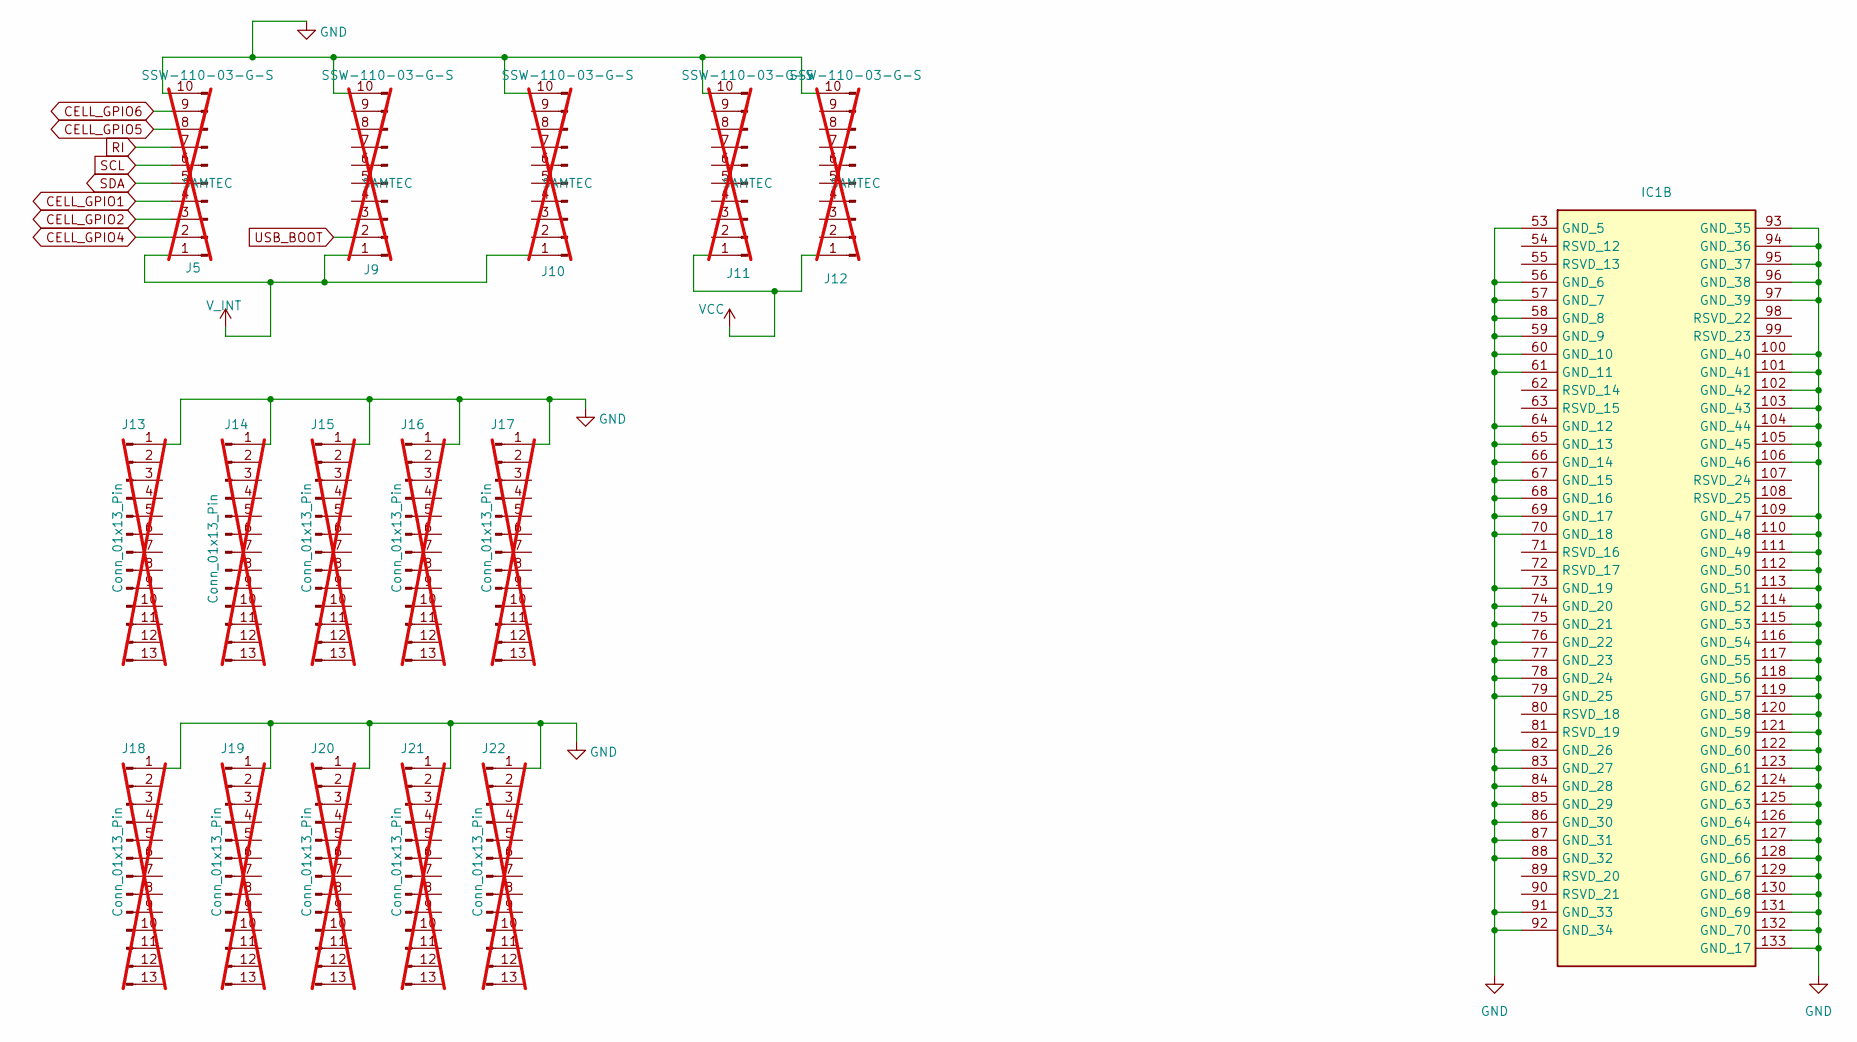
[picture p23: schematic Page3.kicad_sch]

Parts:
IC1: LEXI-R10011D; LEXIR10801D00B00; Manufacturer_Part_Number LEXI-R10011D
J5, J9, J10, J11, J12: SSW-110-03-G-S; SSW-110-03-L-S; Manufacturer_Part_Number SSW-110-03-G-S; not fitted
J13, J14, J15, J16, J17, J18, J19, J20, J21, J22: Conn_01x13_Pin; PinHeader_1x13_P1.27mm_Vertical_minimum_courtyard; not fitted

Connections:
CELL_GPIO1: J5.4; also elsewhere on the board
CELL_GPIO2: J5.3; also elsewhere on the board
CELL_GPIO4: J5.2; also elsewhere on the board
CELL_GPIO5: J5.8; also elsewhere on the board
CELL_GPIO6: J5.9; also elsewhere on the board
GND: IC1.53 (GND_5), IC1.56 (GND_6), IC1.57 (GND_7), IC1.58 (GND_8), IC1.59 (GND_9), IC1.60 (GND_10), IC1.61 (GND_11), IC1.64 (GND_12), IC1.65 (GND_13), IC1.66 (GND_14), IC1.67 (GND_15), IC1.68 (GND_16), IC1.69 (GND_17), IC1.70 (GND_18), IC1.73 (GND_19), IC1.74 (GND_20), IC1.75 (GND_21), IC1.76 (GND_22), IC1.77 (GND_23), IC1.78 (GND_24), IC1.79 (GND_25), IC1.82 (GND_26), IC1.83 (GND_27), IC1.84 (GND_28), IC1.85 (GND_29), IC1.86 (GND_30), IC1.87 (GND_31), IC1.88 (GND_32), IC1.91 (GND_33), IC1.92 (GND_34), IC1.93 (GND_35), IC1.94 (GND_36), IC1.95 (GND_37), IC1.96 (GND_38), IC1.97 (GND_39), IC1.100 (GND_40), IC1.101 (GND_41), IC1.102 (GND_42), IC1.103 (GND_43), IC1.104 (GND_44), IC1.105 (GND_45), IC1.106 (GND_46), IC1.109 (GND_47), IC1.110 (GND_48), IC1.111 (GND_49), IC1.112 (GND_50), IC1.113 (GND_51), IC1.114 (GND_52), IC1.115 (GND_53), IC1.116 (GND_54), IC1.117 (GND_55), IC1.118 (GND_56), IC1.119 (GND_57), IC1.120 (GND_58), IC1.121 (GND_59), IC1.122 (GND_60), IC1.123 (GND_61), IC1.124 (GND_62), IC1.125 (GND_63), IC1.126 (GND_64), IC1.127 (GND_65), IC1.128 (GND_66), IC1.129 (GND_67), IC1.130 (GND_68), IC1.131 (GND_69), IC1.132 (GND_70), IC1.133 (GND_17), J5.10, J9.10, J10.10, J11.10, J12.10, J13.1, J14.1, J15.1, J16.1, J17.1, J18.1, J19.1, J20.1, J21.1, J22.1; also elsewhere on the board
RI: J5.7; also elsewhere on the board
SCL: J5.6; also elsewhere on the board
SDA: J5.5; also elsewhere on the board
USB_BOOT: J9.2; also elsewhere on the board
VCC: J11.1, J12.1; also elsewhere on the board
V_INT: J5.1, J9.1, J10.1; also elsewhere on the board

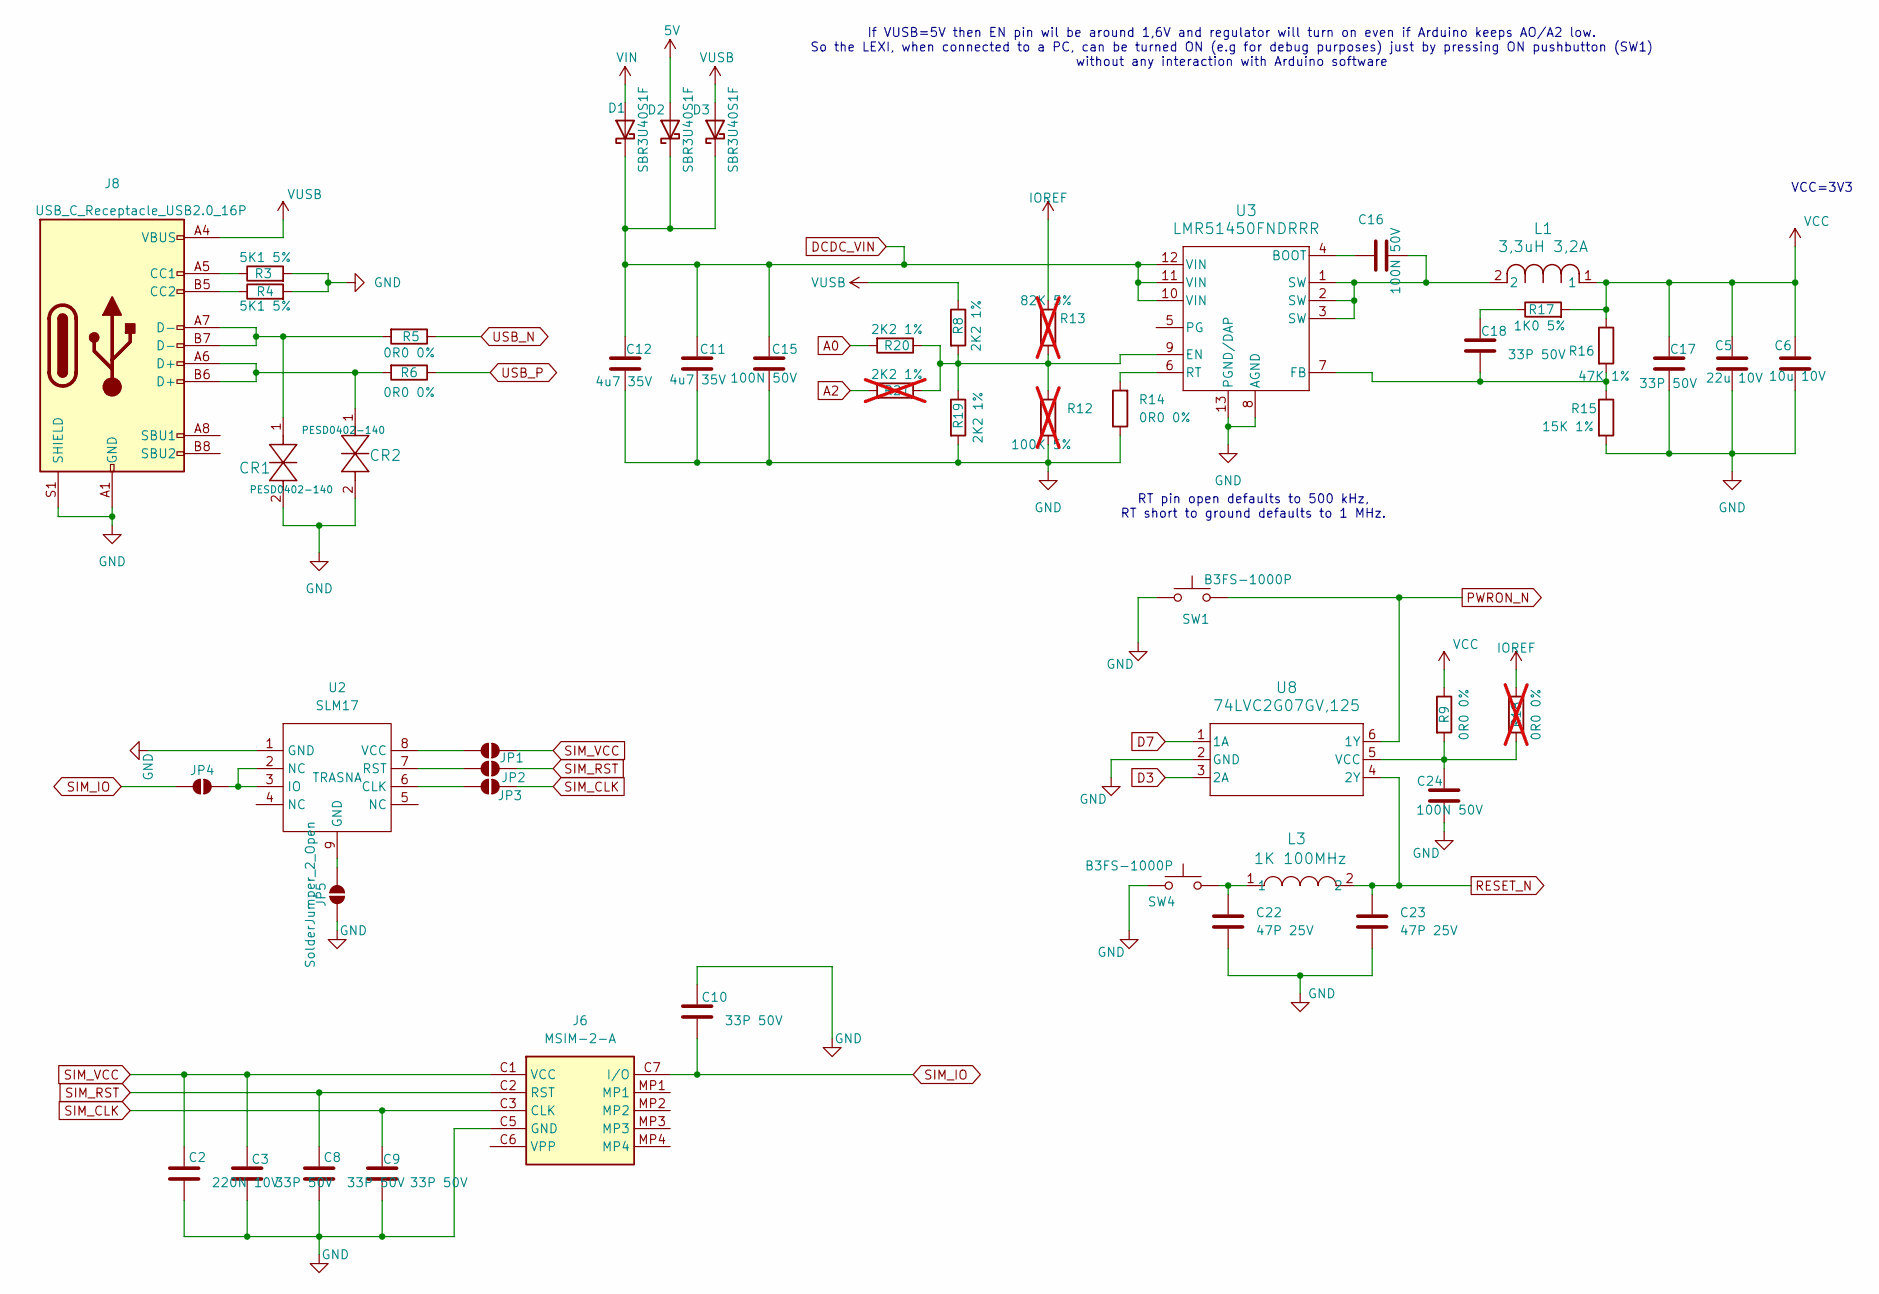
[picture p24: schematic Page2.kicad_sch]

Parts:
C2: 220N 10V; C_0201_0603Metric; Manufacturer_Part_Number GRM033R61A224ME90D
C3, C8, C9, C10, C17, C18: 33P 50V; C_0201_0603Metric; Manufacturer_Part_Number GRM0335C1H330JA01D
C5: 22u 10V; C_0603_1608Metric; Manufacturer_Part_Number GRM188R61A226ME15D
C6: 10u 10V; C_0402_1005Metric; Manufacturer_Part_Number GRM155R61A106ME11D
C11, C12: 4u7 35V; C_0805_2012Metric; Manufacturer_Part_Number GRM21BZ7YA475KE15K
C15, C16, C24: 100N 50V; C_0402_1005Metric; Manufacturer_Part_Number GRM155R61H104KE14D
C22, C23: 47P 25V; C_0201_0603Metric; Manufacturer_Part_Number GRM0335C1H470JA01D
CR1, CR2: PESD0402-140; PESD0402-140_LTF; Manufacturer_Part_Number PESD0402-140
D1, D2, D3: SBR3U40S1F; D_SOD-123F; Manufacturer_Part_Number SBR3U40S1FQ-7
J6: MSIM-2-A; MSIM2A; Mouser Part Number 179-MSIM-2-A
J8: USB_C_Receptacle_USB2.0_16P; USB_C_Receptacle_GCT_USB4105-xx-A_16P_TopMnt_Horizontal; Manufacturer_Part_Number 12402012E212A
JP1, JP2, JP3, JP4, JP5: SolderJumper_2_Open; SolderJumper-2_P1.3mm_Open_RoundedPad1.0x1.5mm
L1: 3,3uH 3,2A; IND_IFSC-2020DE-01_VIS; Manufacturer_Part_Number IFSC2020DEER3R3N01
L3: 1K 100MHz; IND_BLM15_0402_MUR; Manufacturer_Part_Number BLM15HD102SN1D
R3, R4: 5K1 5%; R_0402_1005Metric; Manufacturer_Part_Number RK73B1ETTP512J
R5, R6, R9, R14: 0R0 0%; R_0402_1005Metric; Manufacturer_Part_Number RC0402JR-070RL
R8, R19, R20: 2K2 1%; R_0402_1005Metric; Manufacturer_Part_Number RK73H1ETTP2201F
R12: 100K 5%; R_0402_1005Metric; Manufacturer_Part_Number RC0402JR-07100KL; not fitted
R13: 82K 5%; R_0402_1005Metric; Manufacturer_Part_Number MCR01MZPJ823; not fitted
R15: 15K 1%; R_0402_1005Metric; Manufacturer_Part_Number RK73H1ETTP1502F
R16: 47K 1%; R_0402_1005Metric; Manufacturer_Part_Number RK73H1ETTP4702F
R17: 1K0 5%; R_0402_1005Metric; Manufacturer_Part_Number RK73B1ETTP102J
R18: 0R0 0%; R_0402_1005Metric; Manufacturer_Part_Number RC0402JR-070RL; not fitted
R21: 2K2 1%; R_0402_1005Metric; Manufacturer_Part_Number RK73H1ETTP2201F; not fitted
SW1, SW4: B3FS-1000P; SW_SPST_Omron_B3FS-100xP; Manufacturer_Part_Number B3FS-1000P
U2: SLM17; Infineon_USON_2x2mm_P0.5mm_EP0.9x1.6mm
U3: LMR51450FNDRRR; WSON12-DRR_TEX; Manufacturer_Part_Number LMR51450FNDRRR
U8: 74LVC2G07GV,125; 74LVC2G07GV_125_NEX; Manufacturer_Part_Number 74LVC2G07GV,125

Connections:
5V: D2.2 (A); also elsewhere on the board
A0: R20.2; also elsewhere on the board
A2: R21.2; also elsewhere on the board
D3: U8.3 (2A); also elsewhere on the board
D7: U8.1 (1A); also elsewhere on the board
DCDC_VIN: C11.1, C12.1, C15.1, D1.1 (K), D2.1 (K), D3.1 (K), U3.10 (VIN), U3.11 (VIN), U3.12 (VIN); also elsewhere on the board
GND: C2.2, C3.2, C5.2, C6.2, C8.2, C9.2, C10.1, C11.2, C12.2, C15.2, C17.2, C22.2, C23.2, C24.2, CR1.2, CR2.2, J6.C5 (GND), J8.A1 (GND), J8.A12 (GND), J8.B1 (GND), J8.B12 (GND), J8.S1 (SHIELD), JP5.1 (A), R3.2, R4.2, R12.2, R14.1, R15.2, R19.2, SW1.1, SW4.1, U2.1 (GND), U3.8 (AGND), U3.13 (PGND/DAP), U8.2 (GND); also elsewhere on the board
IOREF: R13.1, R18.1; also elsewhere on the board
unnamed: C16.2, L1.2, U3.1 (SW), U3.2 (SW), U3.3 (SW)
unnamed: C18.1, R17.1
unnamed: C22.1, L3.1, SW4.2
unnamed: CR1.1, J8.A7 (D-), J8.B7 (D-), R5.2
unnamed: CR2.1, J8.A6 (D+), J8.B6 (D+), R6.2
unnamed: J8.A5 (CC1), R3.1
unnamed: J8.B5 (CC2), R4.1
unnamed: JP1.1 (A), U2.8 (VCC)
unnamed: JP2.1 (A), U2.7 (RST)
unnamed: JP3.1 (A), U2.6 (CLK)
unnamed: JP4.2 (B), U2.2 (NC), U2.3 (IO)
unnamed: JP5.2 (B), U2.9 (GND)
unnamed: C16.1, U3.4 (BOOT)
unnamed: R8.2, R12.1, R13.2, R19.1, R20.1, R21.1, U3.9 (EN)
unnamed: C18.2, R15.1, R16.2, U3.7 (FB)
unnamed: R14.2, U3.6 (RT)
unnamed: C24.1, R9.2, R18.2, U8.5 (VCC)
PWRON_N: SW1.2, U8.6 (1Y); also elsewhere on the board
RESET_N: C23.1, L3.2, U8.4 (2Y); also elsewhere on the board
SIM_CLK: C9.1, J6.C3 (CLK), JP3.2 (B); also elsewhere on the board
SIM_IO: C10.2, J6.C7 (I/O), JP4.1 (A); also elsewhere on the board
SIM_RST: C8.1, J6.C2 (RST), JP2.2 (B); also elsewhere on the board
SIM_VCC: C2.1, C3.1, J6.C1 (VCC), JP1.2 (B); also elsewhere on the board
USB_N: R5.1; also elsewhere on the board
USB_P: R6.1; also elsewhere on the board
VCC: C5.1, C6.1, C17.1, L1.1, R9.1, R16.1, R17.2; also elsewhere on the board
VIN: D1.2 (A); also elsewhere on the board
VUSB: D3.2 (A), J8.A4 (VBUS), J8.A9 (VBUS), J8.B4 (VBUS), J8.B9 (VBUS), R8.1

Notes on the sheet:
RT pin open defaults to 500 kHz, RT short to ground defaults to 1 MHz.
If VUSB=5V then EN pin wil be around 1,6V and regulator will turn on even if Arduino keeps AO/A2 low. So the LEXI, when connected to a PC, can be turned ON (e.g for debug purposes) just by pressing ON pushbutton (SW1) without any interaction with Arduino software
VCC=3V3

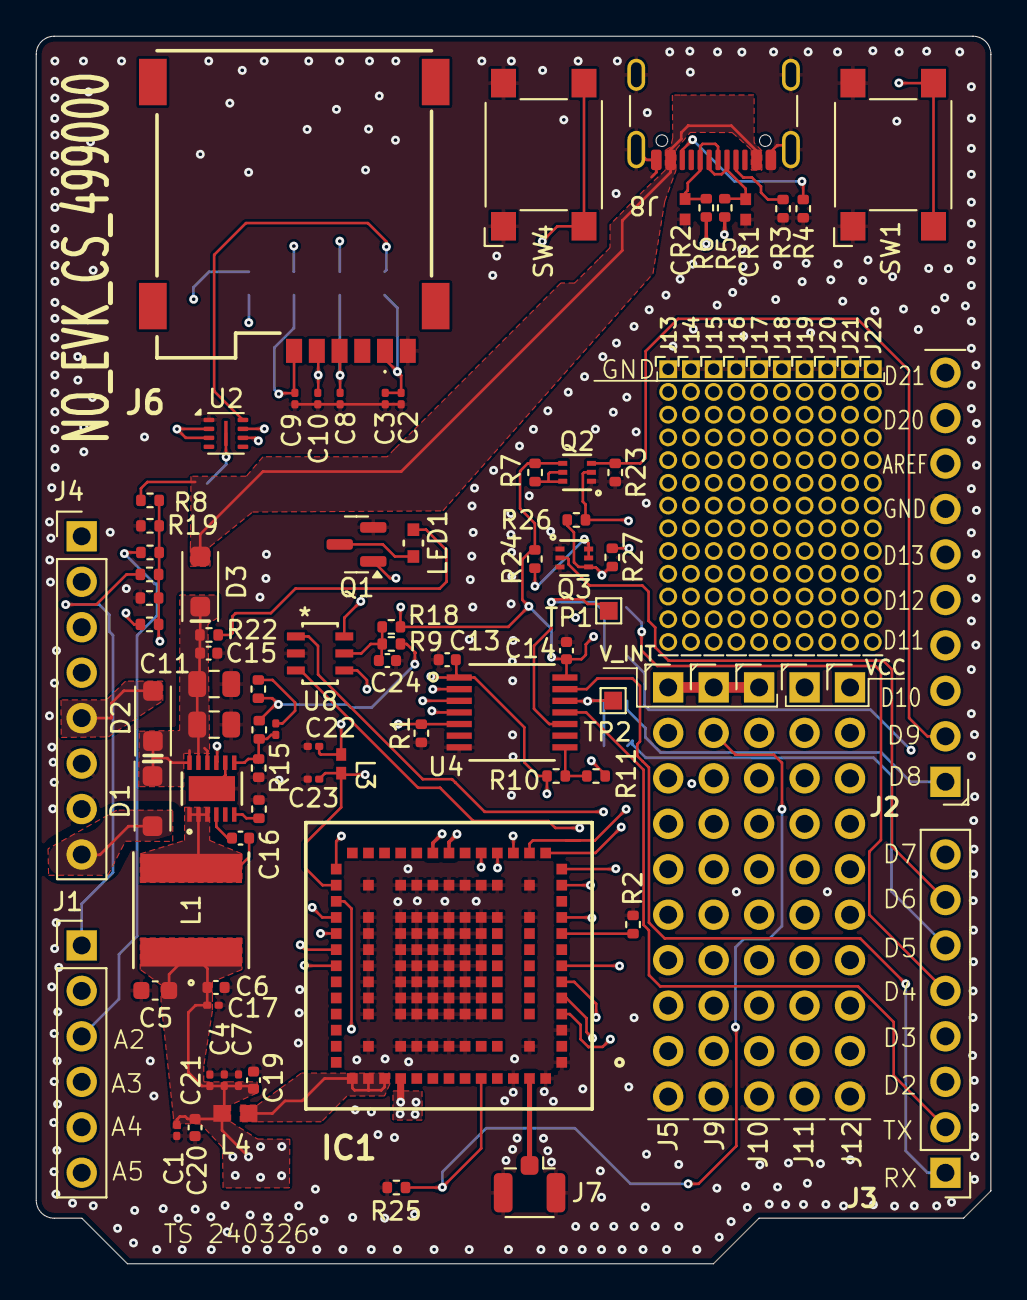
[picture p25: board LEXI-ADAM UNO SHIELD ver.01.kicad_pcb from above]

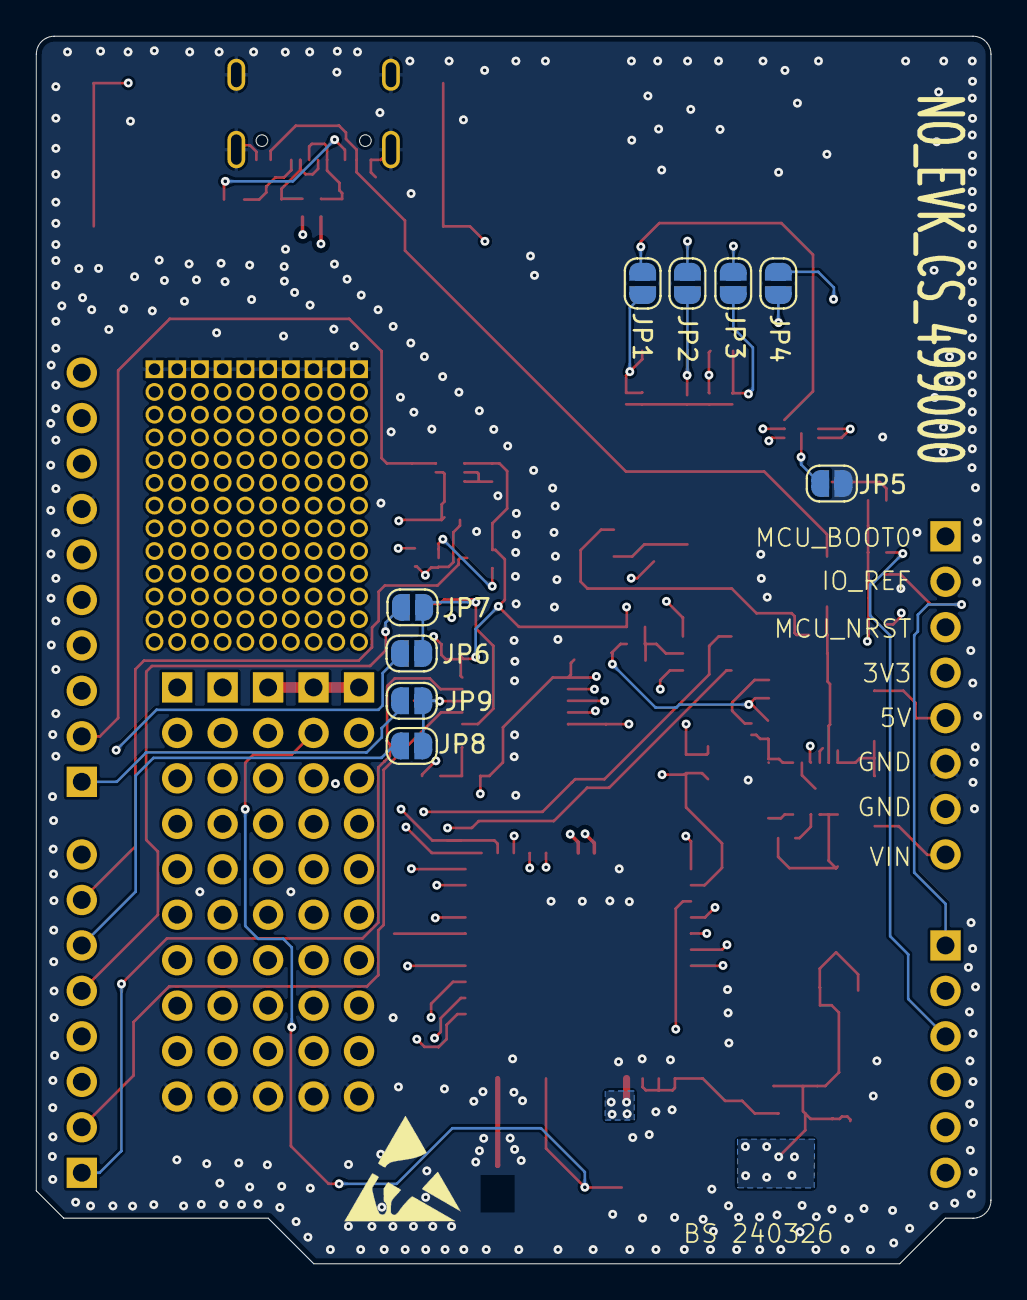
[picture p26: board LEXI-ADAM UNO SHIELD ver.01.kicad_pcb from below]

Board: 4 copper layers, 53.3 x 68.6 mm, 103 parts (9 on the bottom side), 69 nets.

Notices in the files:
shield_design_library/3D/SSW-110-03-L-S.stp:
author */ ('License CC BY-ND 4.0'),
